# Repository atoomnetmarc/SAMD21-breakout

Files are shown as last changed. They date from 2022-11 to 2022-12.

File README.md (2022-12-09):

ATSAMD21G18A-AU breakout board with the physical layout inspired by the `Arduino MKR Zero`.

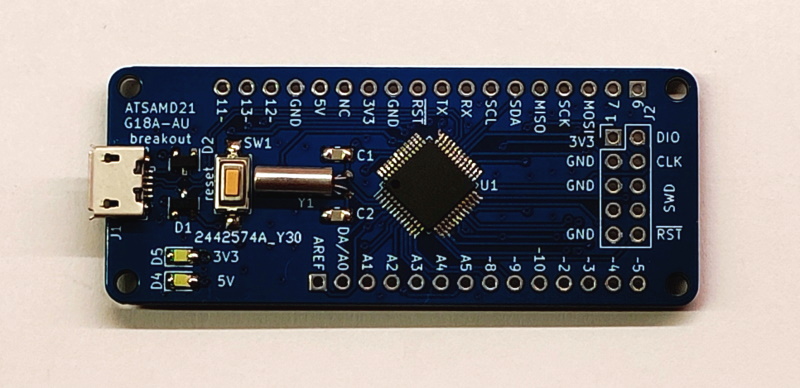
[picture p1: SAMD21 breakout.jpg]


# Power supply

Supply power to 3V3 pin. Or supply power to 5V pin (or USB) and get free 3V3.

# Platformio

`platformio.ini`:
```ini
[env:mzeroUSB]
platform = atmelsam
board = mzeroUSB
```

# Pinout

| Arduino | SAMD21 | Alternate |
| --: | --: | --: |
| AREF | PA03 |
| A0 | PA01 | DAC
| A1 | PB08 |
| A2 | PB09 |
| A3 | PA04 |
| A4 | PA05 |
| A5 | PB02 |
| RX | PA11 | D0
| TX | PA10 | D1
| ~D2 | PA08 | SDA2
| ~D3 | PA09 | SCL2
| ~D4 | PA14 |
| ~D5 | PA15 |
| D6 | PA20 |
| D7 | PA21 |
| ~D8 | PA06 |
| ~D9 | PA07 |
| ~D10 | PA18 |
| ~D11 | PA16 | SDA3
| ~D12 | PA19 |
| ~D13 | PA17 | SCL3
| SDA | PA22 |
| SCL | PA23 |
| MISO | PA12 |
| MOSI | PB10 |
| SCK | PB11 |

# Soldering

Solder every component except U1, J2, J4 and J5. Begin with all the components on the bottom.

Clean board.

Apply current limited (50mA) 5V to GND and 5V pin. Current should be about 6mA. Measure voltage on 3V3 pin, it should be 3.3V. Disconnect. Connect USB, both LEDs should light up again.

Solder U1 carefully. Inspect U1 pins with microscope for shorts or missing soldered pins. Correct when found.

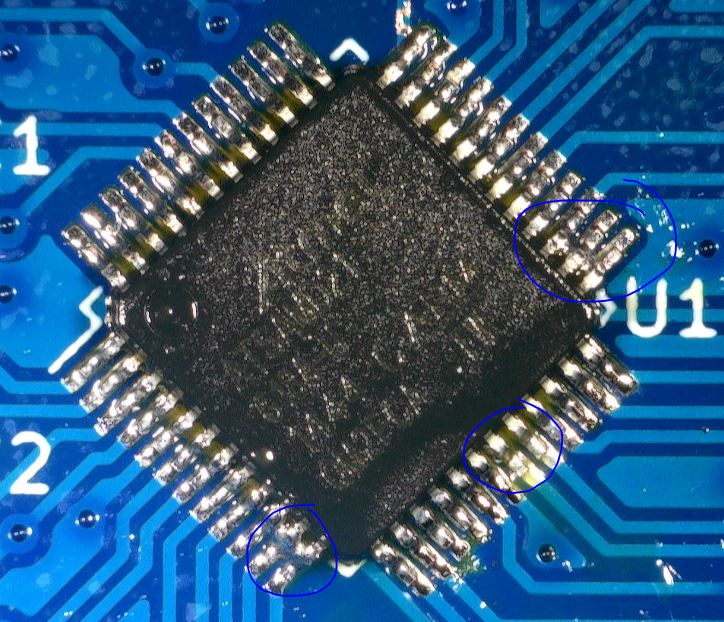
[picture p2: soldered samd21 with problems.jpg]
This SAMD21 needs some work


Clean again. Inspect again.

Measure all adjacent signal pins (on headers J4 and J5) for shorts: XIN21, XOUT32, A0, AREF, GND, 3V3, A1, A2, A3, A4, ~D8, ~D9, ~D2, ~D3, TX, RX, 3V3, GND, MOSI, SCK, MISO, PA13 (U1 pin 22), ~D4, ~D5, ~D11, ~D13, ~D10, ~D12, D6, D7, SDA, SCL, USB- (on D1), USB+ (on D2), GND, 3V3, PB22 (U1 pin 37), PB23 (U1 pin 38), PA27 (U1 pin 39), RST, PA28 (U1 pin 41), GND, VDDCORE (on C21), 3V3, CLK (on J2), DIO (on J2), A5 and PB03 (U1 pin 48). Correct shorts when found.

Apply current limited (50mA) to GND and 5V pin. Current should still be about 6mA.

# Bootloader

Before this board behaves like an `Arduino M0` (that you can program with the USB-port) you must first use the `Burn Bootloader`-function from the Arduino IDE. Choose the board `Arduino M0`, then choose your desired `Programmer` then choose `Burn Bootloader`.

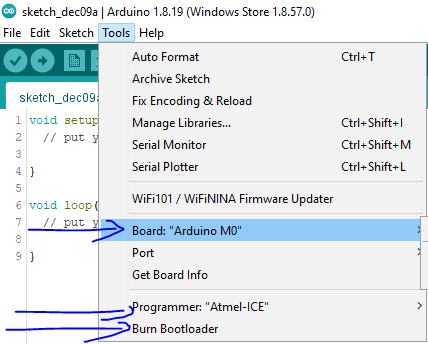
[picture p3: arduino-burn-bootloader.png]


# Invisible Blink

Connect USB. A new serial port should appear in the device manager.

Open the example Blink sketch and flash it to the MCU. Measure voltage on GND and ~D13, it should alternate between 0V and 3.3V.

# Done

Done!



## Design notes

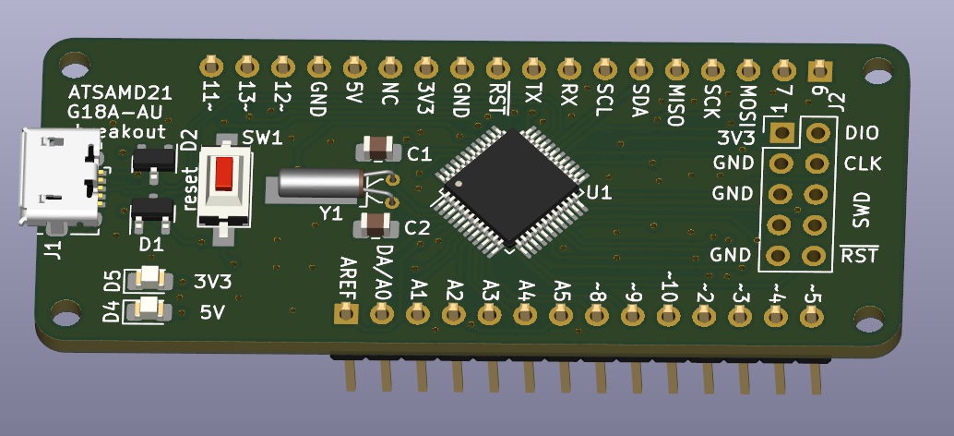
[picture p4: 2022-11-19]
render.png

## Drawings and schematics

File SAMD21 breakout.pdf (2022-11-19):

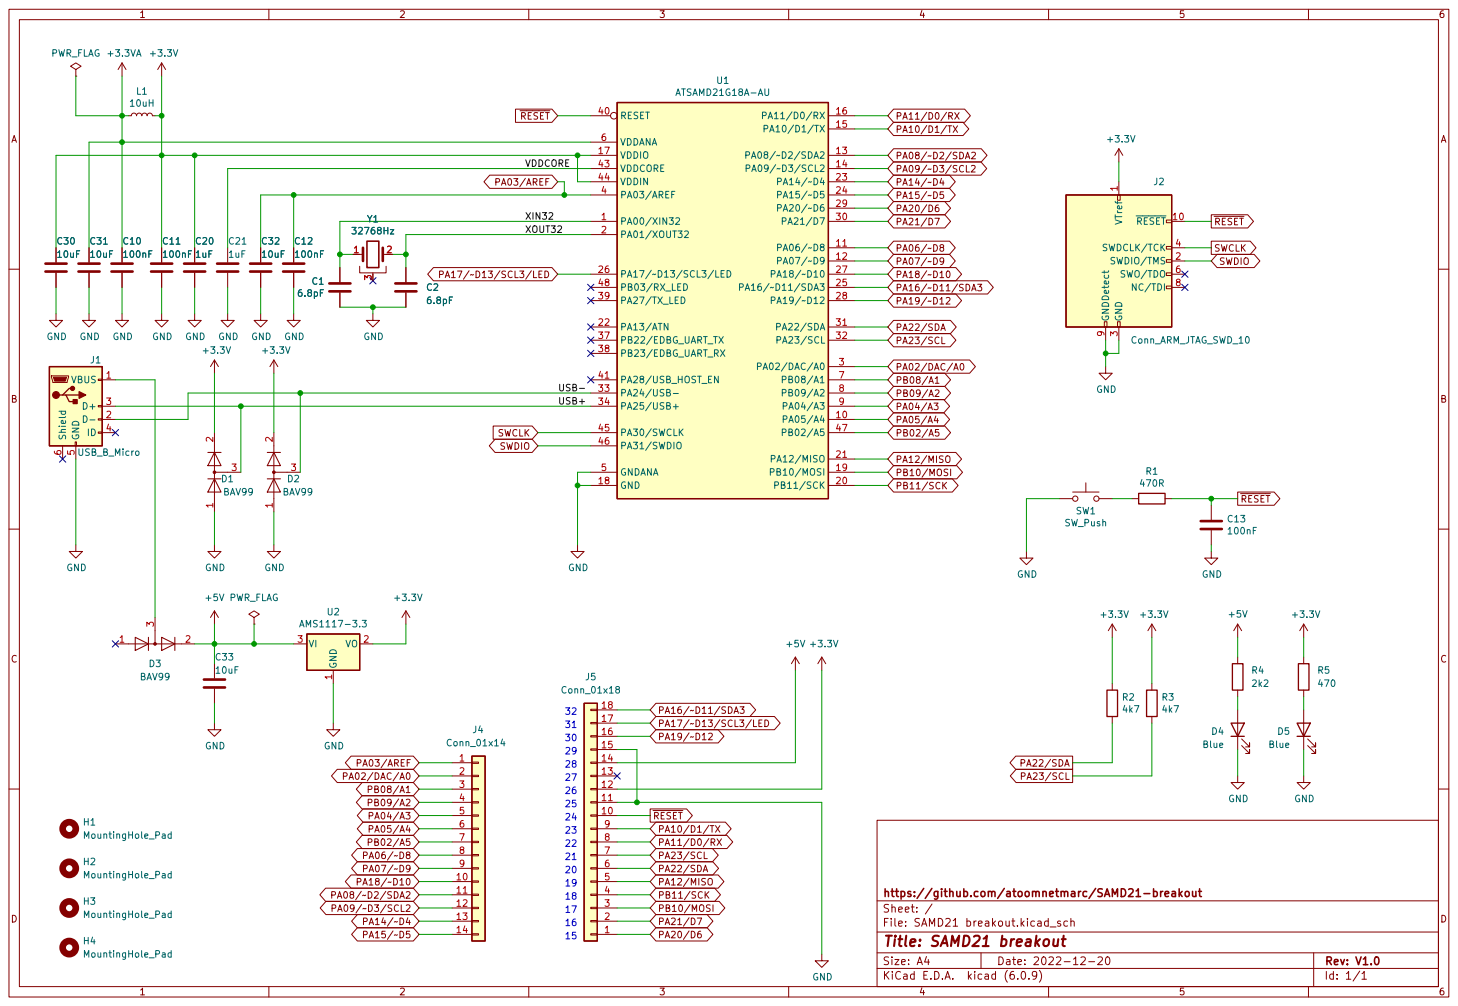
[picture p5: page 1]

3 SWDCLK/TCK 4 SWO/TDO 6 NC/TDI 8 GNDDetect 9

File: SAMD21 breakout.kicad_sch Sheet: / https://github.com/atoomnetmarc/SAMD21-breakout

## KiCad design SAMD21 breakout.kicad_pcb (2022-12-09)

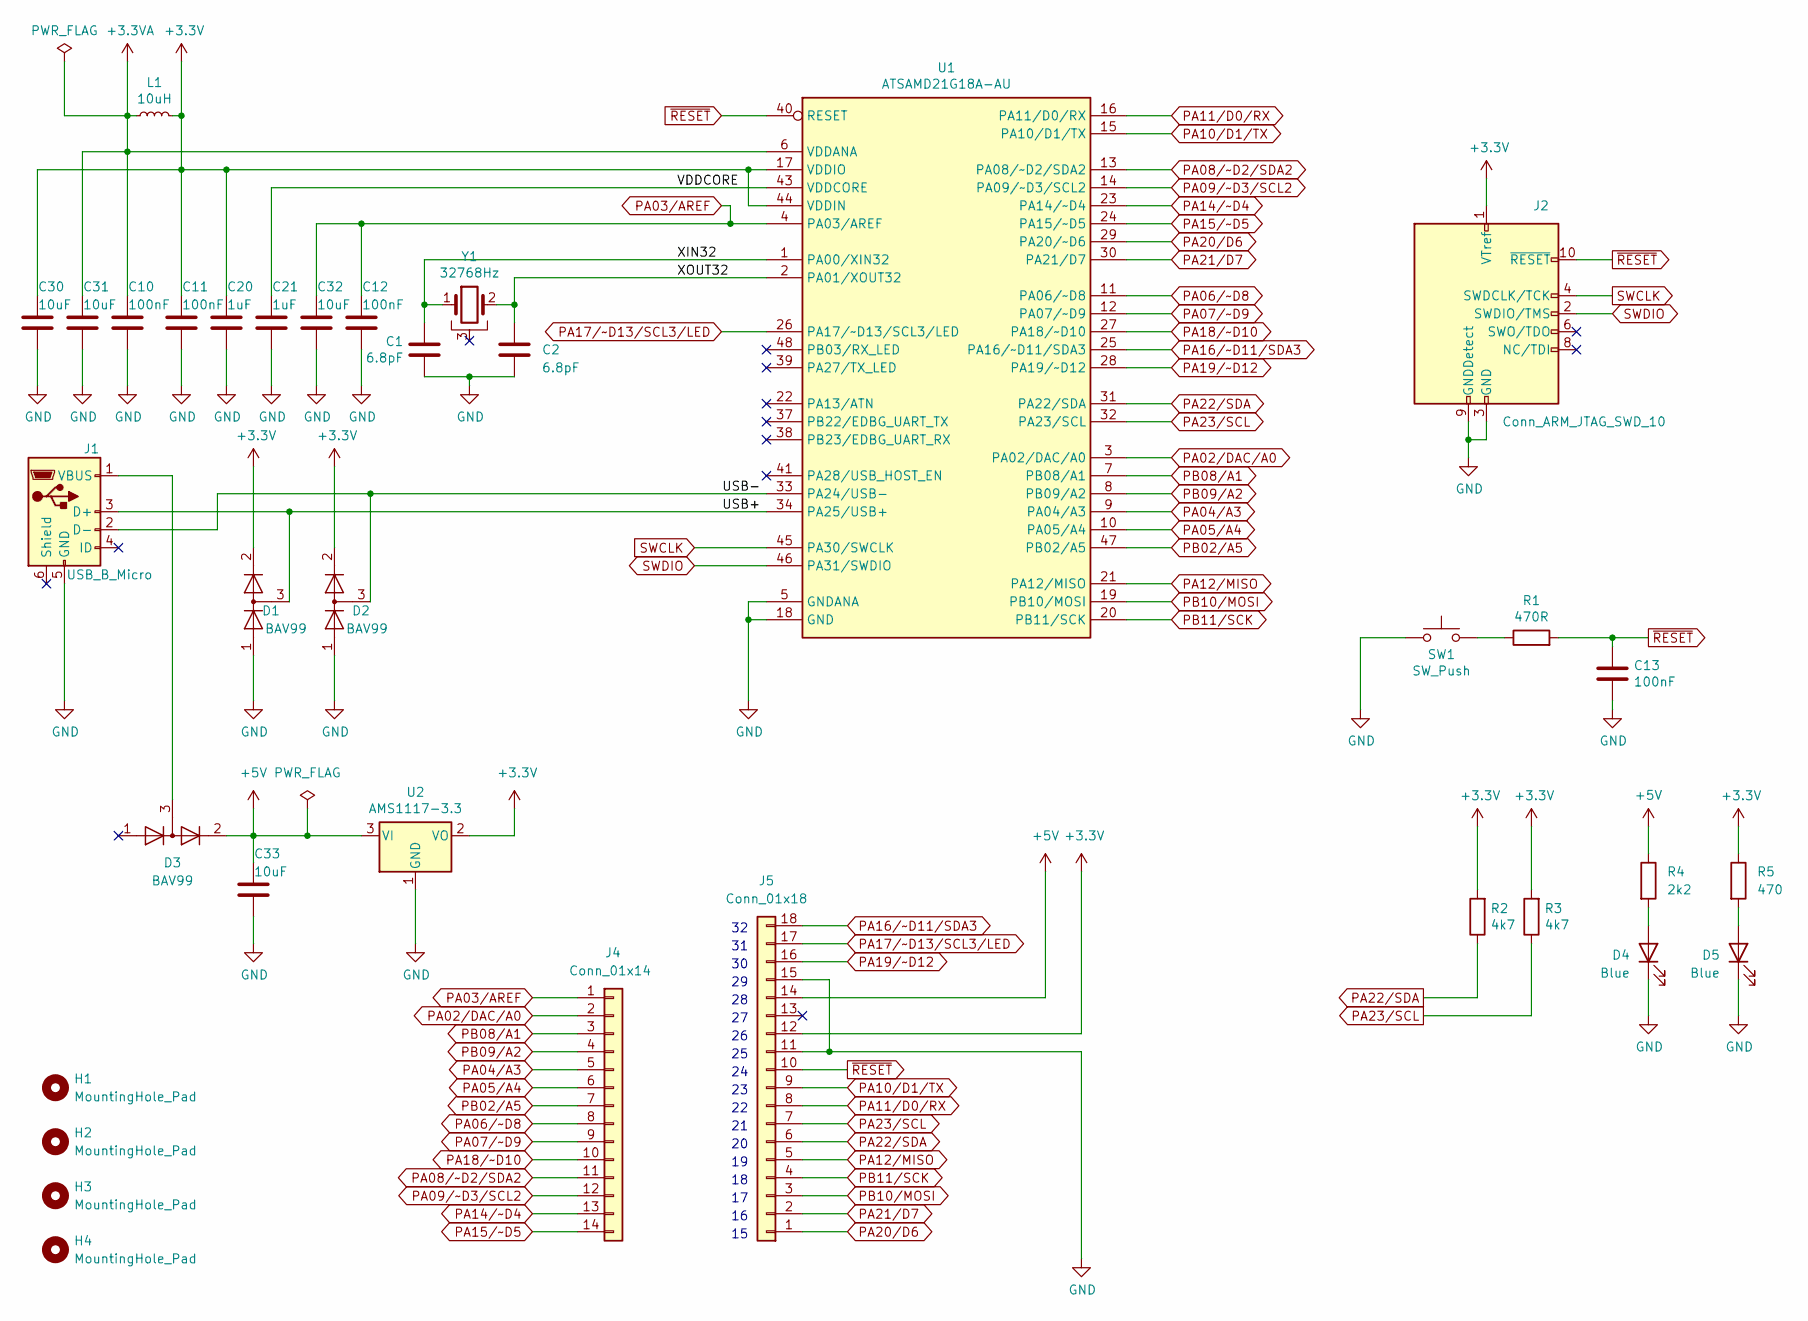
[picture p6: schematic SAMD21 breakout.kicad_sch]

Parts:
C1, C2: 6.8pF; C_0805_2012Metric_Pad1.18x1.45mm_HandSolder
C10, C11, C12, C13: 100nF; C_0805_2012Metric_Pad1.18x1.45mm_HandSolder
C20, C21: 1uF; C_0805_2012Metric_Pad1.18x1.45mm_HandSolder
C30, C31, C32, C33: 10uF; C_0805_2012Metric_Pad1.18x1.45mm_HandSolder
D1, D2, D3: BAV99; SOT-23
D4, D5: Blue; LED_0805_2012Metric_Pad1.15x1.40mm_HandSolder
H1, H2, H3, H4: MountingHole_Pad; MountingHole_2.2mm_M2_DIN965
J1: USB_B_Micro; USB_Micro-B_Amphenol_10118194_Horizontal
J2: Conn_ARM_JTAG_SWD_10; PinHeader_2x05_P2.54mm_Vertical
J4: Conn_01x14; PinHeader_1x14_P2.54mm_Vertical
J5: Conn_01x18; PinHeader_1x18_P2.54mm_Vertical
L1: 10uH; L_0805_2012Metric_Pad1.15x1.40mm_HandSolder
R1: 470R; R_0805_2012Metric_Pad1.20x1.40mm_HandSolder
R2, R3: 4k7; R_0805_2012Metric_Pad1.20x1.40mm_HandSolder
R4: 2k2; R_0805_2012Metric_Pad1.20x1.40mm_HandSolder
R5: 470; R_0805_2012Metric_Pad1.20x1.40mm_HandSolder
SW1: SW_Push; SW_SPST_CK_RS282G05A3
U1: ATSAMD21G18A-AU; TQFP-48_7x7mm_P0.5mm
U2: AMS1117-3.3; SOT-223-3_TabPinNC
Y1: 32768Hz; Crystal_C26-LF_D2.1mm_L6.5mm_Horizontal_1EP_style1

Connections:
+3.3V: C11.1, C20.1, C30.1, D1.2 (A), D2.2 (A), J2.1 (VTref), J5.12, L1.2, R2.2, R3.2, R5.1, U1.17 (VDDIO), U1.36 (VDDIO), U1.44 (VDDIN), U2.2 (VO)
+3.3VA: C10.1, C31.1, L1.1, U1.6 (VDDANA)
+5V: C33.1, D3.2 (A), J5.14, R4.1, U2.3 (VI)
/USB+: D1.3 (K), J1.3 (D+), U1.34 (PA25/USB+)
/USB-: D2.3 (K), J1.2 (D-), U1.33 (PA24/USB-)
/VDDCORE: C21.1, U1.43 (VDDCORE)
/XIN32: C1.1, U1.1 (PA00/XIN32), Y1.1
/XOUT32: C2.1, U1.2 (PA01/XOUT32), Y1.2
GND: C1.2, C2.2, C10.2, C11.2, C12.2, C13.2, C20.2, C21.2, C30.2, C31.2, C32.2, C33.2, D1.1 (K), D2.1 (K), D4.1 (K), D5.1 (K), J1.5 (GND), J2.3 (GND), J2.5 (GND), J2.9 (GNDDetect), J5.11, J5.15, SW1.1, U1.5 (GNDANA), U1.18 (GND), U1.35 (GND), U1.42 (GND), U2.1 (GND)
unnamed: D3.3 (K), J1.1 (VBUS)
unnamed: D4.2 (A), R4.2
unnamed: D5.2 (A), R5.2
unnamed: R1.1, SW1.2
PA02/DAC/A0: J4.2, U1.3 (PA02/DAC/A0)
PA03/AREF: C12.1, C32.1, J4.1, U1.4 (PA03/AREF)
PA04/A3: J4.5, U1.9 (PA04/A3)
PA05/A4: J4.6, U1.10 (PA05/A4)
PA06/~D8: J4.8, U1.11 (PA06/~D8)
PA07/~D9: J4.9, U1.12 (PA07/~D9)
PA08/~D2/SDA2: J4.11, U1.13 (PA08/~D2/SDA2)
PA09/~D3/SCL2: J4.12, U1.14 (PA09/~D3/SCL2)
PA10/D1/TX: J5.9, U1.15 (PA10/D1/TX)
PA11/D0/RX: J5.8, U1.16 (PA11/D0/RX)
PA12/MISO: J5.5, U1.21 (PA12/MISO)
PA14/~D4: J4.13, U1.23 (PA14/~D4)
PA15/~D5: J4.14, U1.24 (PA15/~D5)
PA16/~D11/SDA3: J5.18, U1.25 (PA16/~D11/SDA3)
PA17/~D13/SCL3/LED: J5.17, U1.26 (PA17/~D13/SCL3/LED)
PA18/~D10: J4.10, U1.27 (PA18/~D10)
PA19/~D12: J5.16, U1.28 (PA19/~D12)
PA20/D6: J5.1, U1.29 (PA20/~D6)
PA21/D7: J5.2, U1.30 (PA21/D7)
PA22/SDA: J5.6, R2.1, U1.31 (PA22/SDA)
PA23/SCL: J5.7, R3.1, U1.32 (PA23/SCL)
PB02/A5: J4.7, U1.47 (PB02/A5)
PB08/A1: J4.3, U1.7 (PB08/A1)
PB09/A2: J4.4, U1.8 (PB09/A2)
PB10/MOSI: J5.3, U1.19 (PB10/MOSI)
PB11/SCK: J5.4, U1.20 (PB11/SCK)
SWCLK: J2.4 (SWDCLK/TCK), U1.45 (PA30/SWCLK)
SWDIO: J2.2 (SWDIO/TMS), U1.46 (PA31/SWDIO)
~RESET: C13.1, J2.10 (~RESET), J5.10, R1.2, U1.40 (RESET)

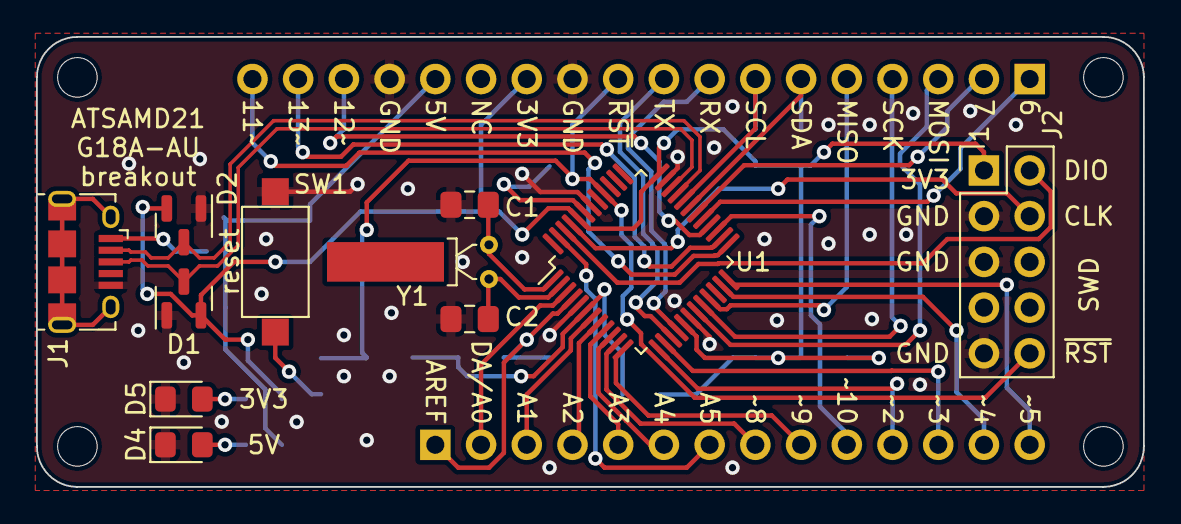
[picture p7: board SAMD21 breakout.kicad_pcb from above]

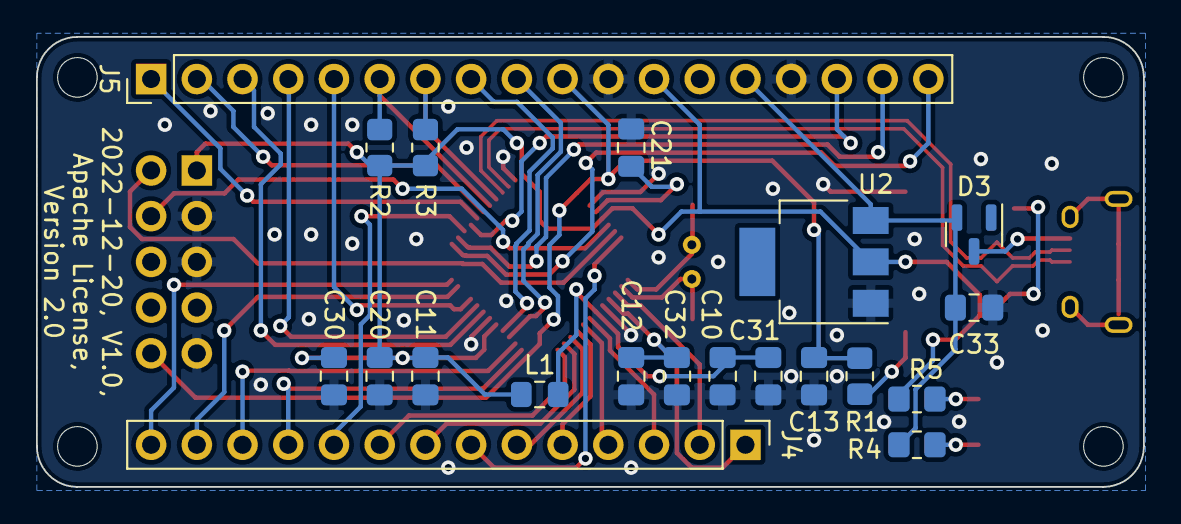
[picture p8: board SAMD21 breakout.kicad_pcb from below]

Board: 2 copper layers, 61.5 x 25.0 mm, 35 parts (20 on the bottom side), 42 nets.

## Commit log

2022-12-09 Mounting holes do not need be on BOM.
    [SAMD21 breakout.kicad_pcb, SAMD21 breakout.kicad_sch]
2022-12-09 Add soldering, test and bootloader instructions.

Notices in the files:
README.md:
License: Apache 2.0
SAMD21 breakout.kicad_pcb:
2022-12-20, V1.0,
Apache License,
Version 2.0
